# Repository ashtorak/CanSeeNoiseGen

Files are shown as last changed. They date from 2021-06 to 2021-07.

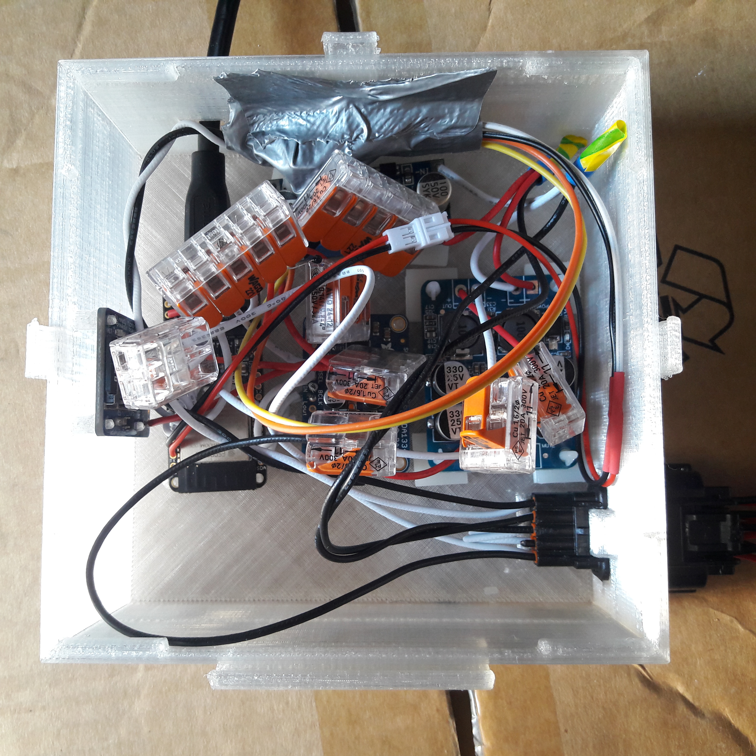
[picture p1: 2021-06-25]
Hardware/20210617_185216.jpg

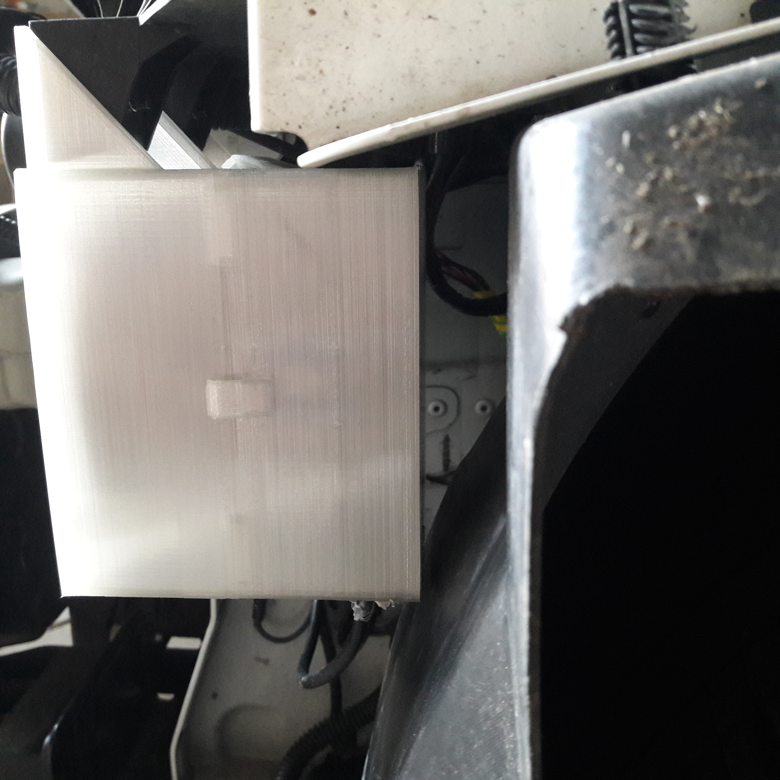
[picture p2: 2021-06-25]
Hardware/20210617_202823.jpg

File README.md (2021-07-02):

# CanSeeNoiseGen
CanSee with Vehicle Noise Generator 3.0 add-on for Renault Zoe (pre 2019 models)

This is an ESP32 project using VSCode with PlatformIO (Arduino framework), CirculaBuffer library and SdFat library. With the latter the build gets too large to use the standard build partition size, so I had to use a custom.csv in the platformio.ini where I set the partition size to 0x200000. See bottom for installation details.  
In my ini I also put some monitor flags and filters, which I tried out for debugging and testing. This is only for the serial interface via USB.

Everything is based on the wonderful work by Jeroen Meijer and co.: https://gitlab.com/jeroenmeijer/cansee

You can connect it to the "V-bus" at the diagnostic OBD port in the car or to the "E-bus" which goes directly to the Zoe VSP (https://canze.fisch.lu/the-pedestrian-horn/)
This NoiseGen software is set up for the E-bus. If you want to use the V-bus, you have to change the code in ticker10ms() in CanSee.ino.  
On E-bus not the same values are sent or different IDs are used. So CanZe won't display all the values.

This has been tested on a 2014 Q210. No guarantee that it works on other models.  
On 2019 or newer models a noise generator is mandatory and an off-switch is not allowed, afaik.

There is an integration with CanZe app in development to control the Noise Generator via bluetooth. But I haven't decided yet what to do with it. I might just release the .apk here.  
In any case, you can use a bluetooth terminal app and send text commands there. See CanSee.ino for reference.

---

**More technical remarks:**

I have to check how to properly connect the I2S board to the ESP. It seems very sensitive, producing crackling on the audio output easily. The best was to make the wires as short as possible. I also found that connecting the AGND directly to the GND of the ESP board seems to help. I am not sure, why.  
The manual for the ESP says to put pullup resistors at the I2S pins. But this didn't do anything for me.

Regarding SD card reading speed, I have tried different boards and combinations and found that the used components give the best speeds up to 25 MHz. If it is too slow (10 MHz), there will be errors when several samples are played in parallel.

---

Short video with some explanations: https://youtu.be/ppg4cpuIZtI

Thread in German Zoe forum with more info in German: https://www.goingelectric.de/forum/viewtopic.php?f=63&t=52091&p=1571585#p1571585

---

**Installation instructions:**

Warning: All here is work in progress. Don't expect everything working right out of the box. Programming experience is necessary. If something is unclear, open an issue or go to the forum.

1. Install VSCode.
2. In VSCode install the PlatformIO IDE extension. 
3. Go to PlatformIO Home (there should appear a bar at the bottom with a house). Then in "Open Project" select this whole folder from Github. Then it should install also the libraries by itself from platformio.ini. Else, you can install them in PIO Home. Also, sometimes it might be necessary to close and open VSCode again so that it finds all the dependencies. 
4. Copy custom.csv to \.platformio\packages\framework-arduinoespressif32\tools\partitions (the program is so large that it needs more memory than default)
5. Connect ESP32 via USB.
6. Build the project and upload it with the buttons on the PIO bar at the bottom.
7. For programming look into CanSee.ino and audiohandler.cpp in the src folder. The file names to load from the SD card are hard coded in the audiohandler. 22050 Hz @ 16 bit audio files are used. You can find the samples in the hardware folder. Just copy the folder content to the SD card.

With the PlatformIO: Serial Monitor or a bluetooth terminal, you can monitor some parameters and give commands that are defined in CanSee.ino.

Attention: The ESP32 and the programm store some configurations options on an EEPROM. For example, you can switch on and off bluetooth and it keeps the state also during power off. When you start the ESP and you don't have bluetooth or the serial output available, it might just be configured like this. See config.cpp for the initial configuration. If you change this configuration later on and upload it to the ESP, in order to actually load the new settings into the EEPROM you have to use the special function setConfigToEeprom(true) or 'z' via the terminal.

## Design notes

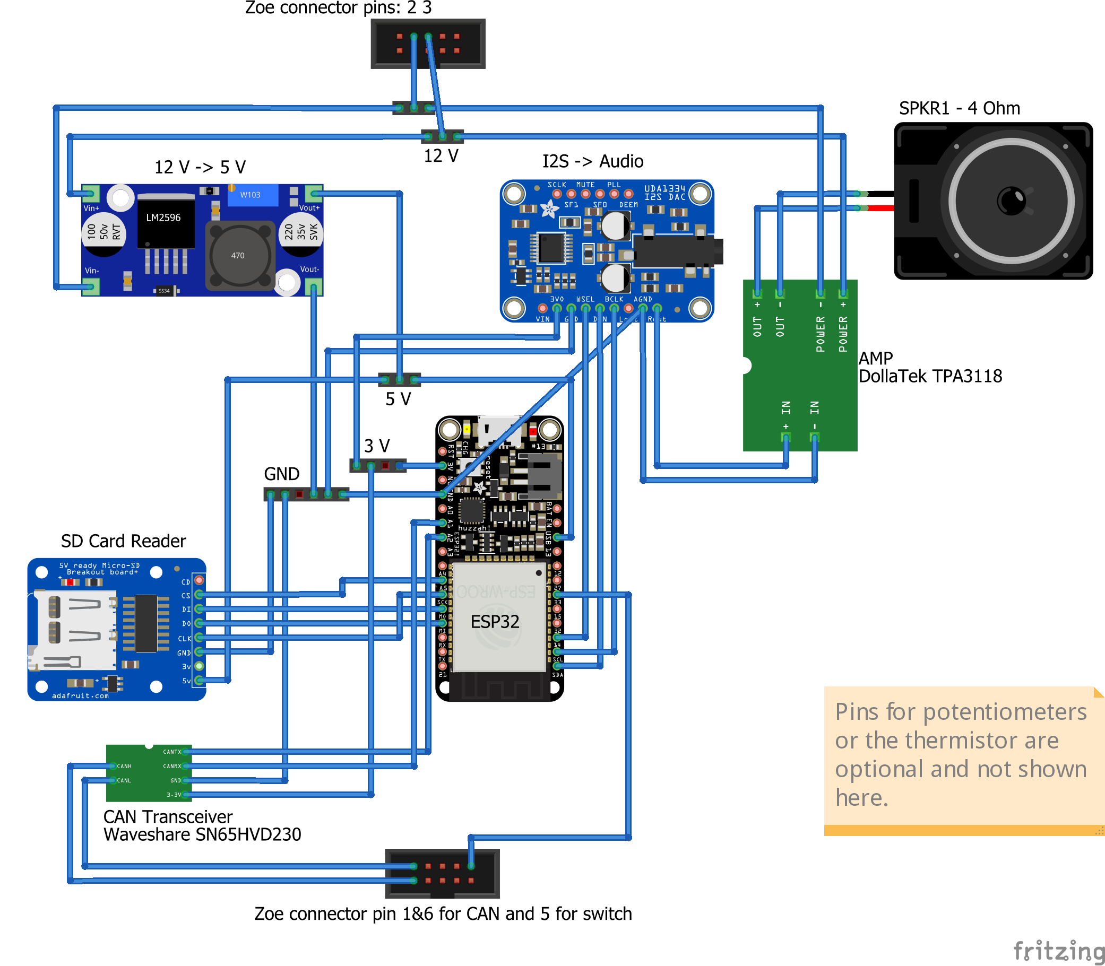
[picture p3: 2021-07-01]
Hardware/schematic.png

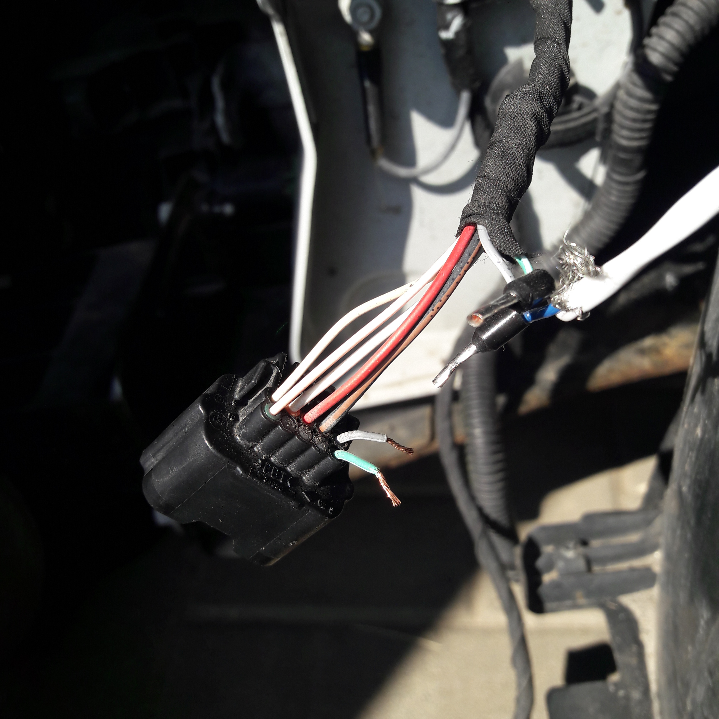
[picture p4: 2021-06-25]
Hardware/ZOE plug.jpg

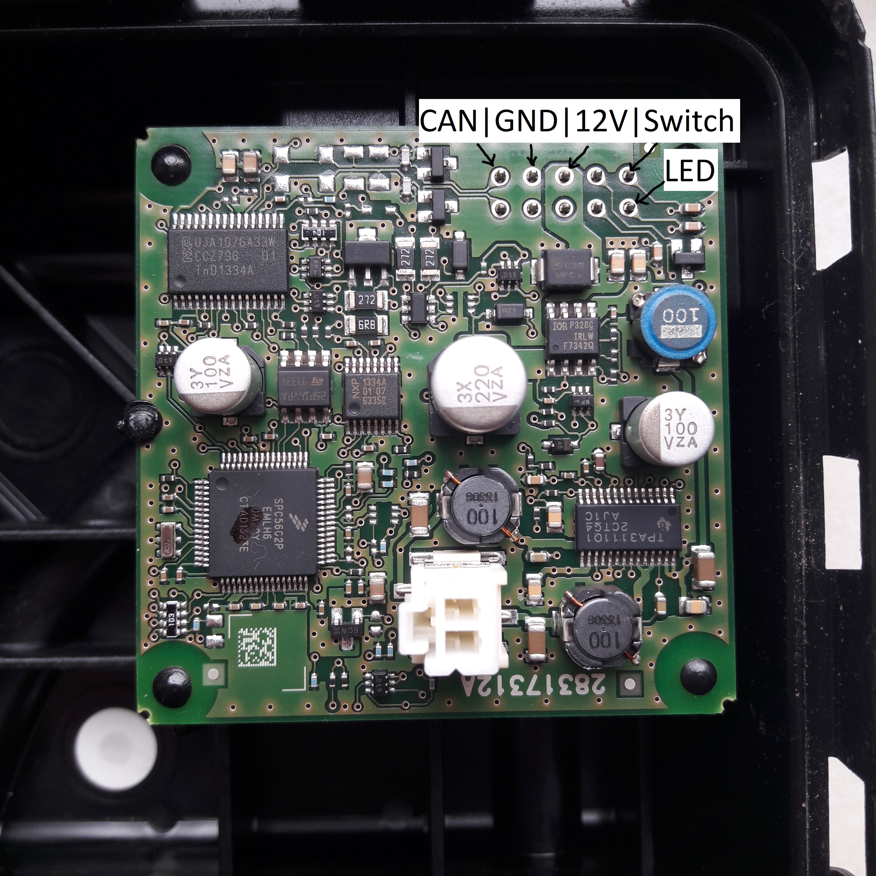
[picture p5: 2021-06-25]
Hardware/ZOE original VSP annotated.jpg

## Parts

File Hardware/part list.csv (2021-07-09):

part | manufacturer number | price in Euro | link
12 V ? 5V | AZDelivery LM2596S | 2,26 € | https://www.amazon.de/gp/product/B07YWLCTLK
I2S Stereo Decoder | Adafruit UDA1334A | 14,90 € | https://www.amazon.de/gp/product/B079GB1Z1M
ESP32 | Adafruit HUZZAH32 | 29,96 € | https://www.amazon.de/gp/product/B0743FNXK5
AMP | DollaTek TPA3118 | 6,99 € | https://www.amazon.de/gp/product/B07DJV4TQ4
SD card reader | Adafruit Micro SD Card Breakout Board+ | 18,56 € | https://www.amazon.de/gp/product/B00G71SN5A
CAN transceiver | Waveshare SN65HVD230 | 12,99 € | https://www.amazon.de/gp/product/B00KM6XMXO
plug | 2sets 10pin auto männlichen elektrische stecker 7282-8856 wasserdichte verdrahtung kabel stecker 7282-8856-30 | 7,00 € | https://de.aliexpress.com/item/33029457017.html

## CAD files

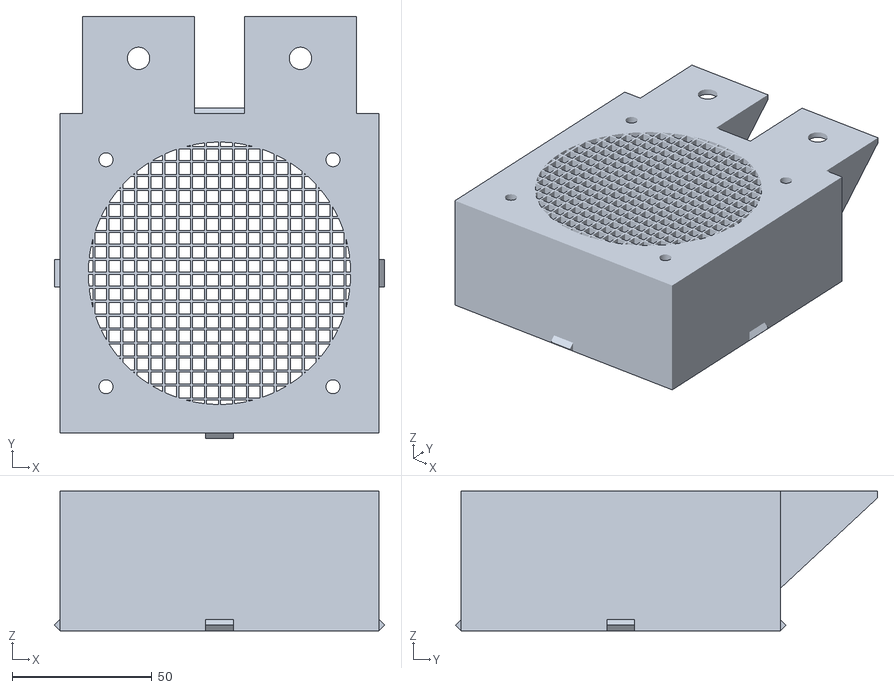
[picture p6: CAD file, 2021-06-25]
Hardware/3d-model-case-speaker.stl
118.4 x 151.2 x 50.0

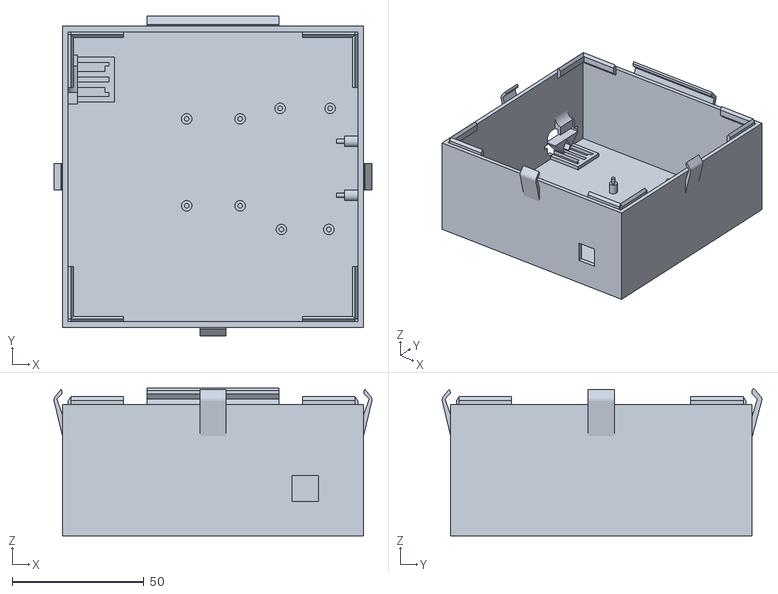
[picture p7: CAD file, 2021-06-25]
Hardware/3d-model-case-electronics.stl
120.8 x 121.4 x 56.2

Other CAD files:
Hardware/3d-freecad-model-case.FCStd

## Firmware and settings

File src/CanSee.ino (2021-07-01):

/*
CanSee with Vehicle Noise Generator add-on

This is based on "The firmware to the DIY, superfast, ESP32 based
comapanion to CANZE dongle" by - The CanZE Team: http://canze.fisch.lu

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
You should have received a copy of the GNU General Public License
along with this program.  If not, see <http://www.gnu.org/licenses/>.
*/

#define VERSION "004"
/* This is using an older CanSee version. It works on a 2014 Q210.
It should work with all Phase 1 ZOEs.
I removed all the LED code, as they are not used for the Noise Generator
*/

#define SERIAL_BPS 115200

/* 

My board: Adafruit HUZZAH32 - ESP32 Feather

CAN bus:
ESP32 GPIO 16 - RX - CAN
ESP32 GPIO 17 - TX - CAN

SD card pins:
ESP32 GPIO 4 - A5 - CS
ESP32 GPIO 5 - SCK
ESP32 GPIO 19 - MI - MISO
ESP32 GPIO 18 - MO -  MOSI

I2S pins:
ESP32 GPIO 22 - SCL - Bit Clock
ESP32 GPIO 14 - A6 - wclk, Left/Right Clock
ESP32 GPIO 23 - SDA - Data Out

Misc pins:
ESP32 GPIO 25 - A1 - potiPin1 (see audiohandler)
ESP32 GPIO 26 - A0 - potiPin2 or for Thermistor
ESP32 GPIO 33 - A9 - sampleSetSelectorPin

*/

// Our own includes, see ./include/ ******************************************
#include "Arduino.h"
#include "config.h"
#include "canhandler.h"
#include "serialhandler.h"
#include "bluetoothhandler.h"
#include "wifihandler.h"
#include "freeframehandler.h"
#include "isotphandler.h"
#include "utils.h"
#include "audiohandler.h"

// for reading out bus values ************************************************
FREEFRAME_t *freeframe;
int byte1 = 0;
int byte2 = 0;
bool pollFrame = false;
int pollFrameId;

// Temperature measurement with thermistor ***********************************
static bool usethermistor = true;
// which analog pin to connect
#define THERMISTORPIN A0         
// resistance at 25 degrees C
#define THERMISTORNOMINAL 10000      
// temp. for nominal resistance (almost always 25 C)
#define TEMPERATURENOMINAL 25   
// how many samples to take and average, more takes longer
// but is more 'smooth'
#define NUMTEMPSAMPLES 5
// The beta coefficient of the thermistor (usually 3000-4000)
#define BCOEFFICIENT 3950
// the value of the 'other' resistor
#define SERIESRESISTOR 10000    

int temperature_samples[5];

// For Zoe capacitive switch for sample selection ****************************

#include <CircularBuffer.h> // add via PlatformIO manager
// it probably could be done without this library but I used it for testing and kept it
static const int touchBuffersize = 50;
/* The touchRead() function reads a number of sawtooths on a pin to see if the 
  capacity changes. The readings fluctuate quite a bit. So it's necessary to 
  average over larger number of samples which are stored in this buffer
*/
CircularBuffer<int, touchBuffersize> touchBuffer;
static const int sampleSetSelectorPin = 33;
int avg;

// Tidy up defs **************************************************************
#if !defined(CONFIG_BT_ENABLED) || !defined(CONFIG_BLUEDROID_ENABLED)
#error Bluetooth is not enabled! Please run `make menuconfig` to and enable it
#endif

// Config ********************************************************************
CS_CONFIG_t *cansee_config;

// Command structure that defines a textual incoming command *****************
typedef struct
{
  char cmd;
  uint32_t id = 0;
  uint8_t request[32];
  uint16_t requestLength = 0;
  uint8_t reply[32];
  uint16_t replyLength = 0;
  char line[48];
} COMMAND_t;

// additional command stuff  *************************************************
String readBuffer = "";
bool pedalCommand = false; // from bluetooth, for sound mod
bool debugaudio = false; // can be changed by command 'x'

//* counters *****************************************************************
uint32_t canFrameCounter = 1;
uint32_t lastCanFrameCounter = 0;
uint32_t cnt5000 = 0;
uint32_t cnt100 = 0;

// ***************************************************************************
void setup()
{
  Serial.begin(SERIAL_BPS); // init serial
  Serial.println("");
  Serial.println(":D");
  Serial.println("CANSee starting...");

  cansee_config = getConfig(); // invalid config will reset too

  cansee_config->output_handler = writeOutgoing;
  cansee_config->command_handler = processCommand;

  if (cansee_config->mode_debug)
  {
    Serial.print("Version:   ");
    Serial.println(VERSION);
    Serial.println("Serial:    " + getHex(cansee_config->mode_serial));
    Serial.println("Bluetooth: " + getHex(cansee_config->mode_bluetooth));
    Serial.println("WiFi:      " + getHex(cansee_config->mode_wifi));
    Serial.println("Debug:     " + getHex(cansee_config->mode_debug));
    Serial.println("CANbus0:   " + getHex(cansee_config->can0_speed / 25) + getHex(cansee_config->can0_rx) + getHex(cansee_config->can0_tx));
    //Serial.println("CANbus1*   " + getHex(cansee_config->can1_speed / 25) + getHex(cansee_config->can1_rx) + getHex(cansee_config->can1_tx));
    Serial.println("Boot count:" + getHex(cansee_config->boot_count));
  }
  cansee_config->boot_count++;

  setConfigToEeprom(false); // use command 'z' during operation to update Eeprom

  serial_init();
  bluetooth_init();
  wifi_init();

  can_init();
  freeframe_init();
  isotp_init();

  audio_init();

  // for measuring as long as possible on Zoe switch
  touchSetCycles(0x9999,0x10);
}

// ***************************************************************************
void loop()
{
  tickerFast();
}

void tickerFast()
{
  uint32_t nowMicros = micros();
  static uint32_t lastMicros = nowMicros; // static so should only be initalized once

  // do Fast
  CAN_frame_t rx_frame; // 1. receive next CAN frame from queue
  if (can_receive(&rx_frame))
  {
    storeFrame(rx_frame);
    canFrameCounter++;
  }
  readIncoming(); // 2. proceed with input (serial & BT)
  isotp_ticker();
  
  audio_fast();
  
// end do Fast

  if ((nowMicros - lastMicros) > 10000L)
  { // 10 ms passed?
    ticker10ms();
    //lastMicros = nowMicros;
    lastMicros += 10000L;
  }
}

void ticker10ms()
{
  static int pedal = 0;

  if(!pedalCommand) // sent via bluetooth
  {
    // get pedal data from e-bus
    freeframe = getFreeframe(0x436, 0);
    pedal = freeframe->data[4];
  }
  else
  { // play sample once with this pedal position (e.g. for horse whinny)
    pedalCommand = false;
    pedal = 100;
  }
  
  // get rpm data from e-bus
  static int elecRPM = 0;
  freeframe = getFreeframe(0x19f, 0); // bits 16 to 27
  byte1 = freeframe->data[2];
  byte2 = freeframe->data[3];
  if(byte1==0) elecRPM = 0; // when not connected to bus
  else elecRPM = abs((byte1<<4 | byte2>>4)*10-20000); 
     
  // get pedal data from v-bus
  // freeframe = getFreeframe(0x186, 0); // position of accelerator pedal, from bit 40 to 48, range 0...250
  // pedal = freeframe->data[5];
    
  // get rpm data from v-bus
  // freeframe = getFreeframe(1f8, 0); // 0x1f8, from bit 40 up to and including 50, range 0...1200 (multiply by 10 for rpm)
  // byte1 = freeframe->data[5]; // bit 40 to 47
  // byte2 = freeframe->data[6]; // bit 48 to 55
  // elecRPM = (byte1<<3 | byte2>>5)*10; // combine 0111 1111 1000 and 0111    

  audio_soundModulator(pedal, elecRPM);
  
  touch();
  
  static int tick = 0;
  
  if (++tick == 100)
  { 
    ticker1000ms();
    tick = 0;
    //Serial.println(sampleSet);
  }
  if(tick==10 && debugaudio)
  {  
    writeOutgoing(audio_debug1());
    writeOutgoing(audio_debug2());
    writeOutgoing("avg: " + String(avg) + "\n");
  }

  // poll a frame (with 'p')
  if(pollFrame)
  {
    requestFreeframe(pollFrameId, 0);
  }
}

void ticker1000ms()
{
  static int tick = 0;

  // do every 1000ms

  // end do every 1000 ms

  if (++tick == 5)
  {
    ticker5000ms();
    tick = 0;
  }

  if (debugaudio && usethermistor)
  {
    static uint8_t i;
    static float average;

    // take N samples in a row, with a slight delay
    for (i=0; i< NUMTEMPSAMPLES; i++) {
    temperature_samples[i] = analogRead(THERMISTORPIN);
   // delay(10);
    }
    
    // average all the samples out
    average = 0;
    for (i=0; i< NUMTEMPSAMPLES; i++) {
      average += temperature_samples[i];
    }
    average /= NUMTEMPSAMPLES;

   // Serial.print("Average analog reading "); 
   // Serial.println(average);
    
    // convert the value to resistance
    average = (4095-200) / average - 1;
    average = SERIESRESISTOR / average;
   // Serial.print("Thermistor resistance "); 
   // Serial.println(average);
    
    float steinhart;
    steinhart = average / THERMISTORNOMINAL;     // (R/Ro)
    steinhart = log(steinhart);                  // ln(R/Ro)
    steinhart /= BCOEFFICIENT;                   // 1/B * ln(R/Ro)
    steinhart += 1.0 / (TEMPERATURENOMINAL + 273.15); // + (1/To)
    steinhart = 1.0 / steinhart;                 // Invert
    steinhart -= 273.15;                         // convert absolute temp to C
    
   // Serial.print("Temperature "); 
  //  Serial.print(steinhart);
  //  Serial.println(" *C");
  writeOutgoing("temperature: " + String(steinhart) + "\n");
  }
}

void ticker5000ms()
{
  // do every 5000ms
  setActiveBluetooth(canFrameCounter != lastCanFrameCounter);
  ageFreeFrame();
  // end do every 5000 ms
}

/*****************************************************************************
* frame handling function
*/

void storeFrame(CAN_frame_t &frame)
{
  if (frame.MsgID < 0x700)
  { // free data is < 0x700
    storeFreeframe(frame, 0);
  }
  else
  { // iso-tp data is < 0x800
    storeIsotpframe(frame, 0);
  }
}

// I/O functions *************************************************************

void writeOutgoing(String o)
{
  writeOutgoingSerial(o);
  writeOutgoingBluetooth(o);
  writeOutgoingWiFi(o);
}

void readIncoming()
{
  readIncomingSerial(readBuffer);
  readIncomingBluetooth(readBuffer);
  readIncomingWiFi(readBuffer);
}

// execute a command *********************************************************
void processCommand()
{
  uint8_t bus = 0;

  if (cansee_config->mode_debug & DEBUG_COMMAND)
    Serial.println("< com:" + readBuffer);
  COMMAND_t command = decodeCommand(readBuffer); // watch out, passe dby reference, so eaten

  //bus = (command.id & 0x40000000) ? 1 : 0;
  //command.id &= 0x1fffffff;                        // allow for 29 bits CAN later

  switch (command.cmd)
  {

  // output all buffered frames ********************************************
  case 'a':
  {
    int count = 0;
    
    for (uint32_t id = 0; id < FREEFRAMEARRAYSIZE; id++)
    {
      freeframe = getFreeframe(id, bus); // bus is ignored for free frames
      if (freeframe->age)
      { // print length 0 frames, but do not print timeout frames
        //writeOutgoing (bufferedFrameToString (id, bus)); // includes \n
        requestFreeframe(id, bus);
        count++;
      }
    }
    if (cansee_config->mode_debug & DEBUG_COMMAND)
      Serial.println("> fcn:" + String(count));
  }
  break;

  // get a frame ***********************************************************
  case 'g':
    if (command.id < FREEFRAMEARRAYSIZE)
    {
      requestFreeframe(command.id, bus);
    }
    else
    {
      if (cansee_config->mode_debug & DEBUG_COMMAND)
        Serial.print("> com:ID out of bounds (0 - 0x6ff)");
      requestFreeframe(0, bus);
    }
    break;

  // request an ISO-TP frame ***********************************************
  case 'i':
    if (command.id >= 0x700)
    {
      requestIsotp(command.id, command.requestLength, command.request, bus);
    }
    else
    {
      if (cansee_config->mode_debug)
        Serial.println("E:ID out of bounds (0x700 - 0x7ff)");
      requestIsotp(0, 0, 0, 0);
    }
    break;

  // inject a frame via serial / BT input **********************************
  case 't':
  {
    CAN_frame_t frame;
    frame.MsgID = command.id;
    frame.FIR.B.DLC = command.requestLength;
    for (int i = 0; i < command.requestLength; i++)
      frame.data.u8[i] = command.request[i];
    if (cansee_config->mode_debug & DEBUG_COMMAND)
      Serial.print("> com:Injecting " + canFrameToString(frame));
    storeFrame(frame);
    // storeframe will output if free frame or ISO-TP Single
    // writeOutgoing (getHex (command.id) + "\n");
  }
  break;

  // config (see config.cpp) ***********************************************
  case 'n':
    if (cansee_config->mode_debug & DEBUG_COMMAND)
      Serial.println("> com:config " + getHex(command.id));
    switch (command.id)
    {
    case 0x100: // set mode flags
      cansee_config->mode_serial = command.request[0];
      cansee_config->mode_bluetooth = command.request[1];
      cansee_config->mode_wifi = command.request[2];
      cansee_config->mode_debug = command.request[3];
      break;
    case 0x101: // get mode flags
      writeOutgoing(getHex(command.id) + "," + getHex(cansee_config->mode_serial) + getHex(cansee_config->mode_bluetooth) + getHex(cansee_config->mode_wifi) + getHex(cansee_config->mode_debug) + "\n");
      return;
      break;
    case 0x110: // set only serial flag
      cansee_config->mode_serial = command.request[0];
      break;
    case 0x114: // set only debug flags
      cansee_config->mode_debug = command.request[0];
      break;
    case 0x200:
      strncpy(cansee_config->name_bluetooth, command.line + 5, sizeof(cansee_config->name_bluetooth));
      break;
    case 0x201:
      strncpy(cansee_config->pin_bluetooth, command.line + 5, sizeof(cansee_config->pin_bluetooth));
      break;
    case 0x300:
      strncpy(cansee_config->ssid_ap, command.line + 5, sizeof(cansee_config->ssid_ap));
      break;
    case 0x301:
      strncpy(cansee_config->password_ap, command.line + 5, sizeof(cansee_config->password_ap));
      break;
    case 0x400:
      strncpy(cansee_config->ssid_station, command.line + 5, sizeof(cansee_config->ssid_station));
      break;
    case 0x401:
      strncpy(cansee_config->password_station, command.line + 5, sizeof(cansee_config->password_station));
      break;
    case 0x500: // can0
      cansee_config->can0_speed = command.request[0] * 25;
      cansee_config->can0_rx = command.request[1];
      cansee_config->can0_tx = command.request[2];
      break;
    case 0x501: // can1
      cansee_config->can1_speed = command.request[0] * 25;
      cansee_config->can1_rx = command.request[1];
      cansee_config->can1_tx = command.request[2];
      break;
    }
    setConfigToEeprom(false);
    writeOutgoing(getHex(command.id) + "\n");
    break;

  // send a value for testing*************************************************
  case 'o':
    audio_test(command.id,0,0);
  break;

  // enable/disable frame polling ********************************************
  case 'p':
  {
    if (command.id < FREEFRAMEARRAYSIZE)
    {
      pollFrameId = command.id;
      if (pollFrameId == 0) pollFrame = false;
      else pollFrame = true;
    }
  }
  break;

  // send a value for testing*************************************************
  case 'q':
    audio_test(0,command.id,0);
  break;

  // reset config & reboot **************************************************
  case 'r':
    ESP.restart();
  break;

  // sample select **********************************************************
  case 's':
    audio_selectSampleSet(command.id);
  break;

  // adjust global volume ***************************************************
  case 'v':
    if(command.id<16) audio_setVolume(command.id);
    else audio_setVolume(command.id-6);
  break;

  // medium pedal press for sound simulation (whinny)************************
  case 'w':
    pedalCommand = true;
  break;

  // write audio info to outgoing********************************************
  case 'x':
    debugaudio=!debugaudio;
  break;

  // send a value for testing************************************************
  case 'y':
    audio_test(0,0,command.id);
  break;

  // reboot *****************************************************************
  case 'z':
    setConfigToEeprom(true);
    ESP.restart();
    break;

  // give up ****************************************************************
  default:
    if (cansee_config->mode_debug)
      Serial.println("> com:Unknown command " + String(command.cmd));
    writeOutgoing("fff,\n");
    break;
  }
}

// parse a string into a command *********************************************
COMMAND_t decodeCommand(String &input)
{
  COMMAND_t result;
  result.id = 0; // clear out older data
  result.requestLength = 0;
  result.replyLength = 0;

  input.trim(); // trim whitespaces
  strncpy(result.line, input.c_str(), sizeof(result.line));

  if (input.length() == 0)
    return result; // stop if input is empty

  result.cmd = input.charAt(0); // the first letter is the command
  input.remove(0, 1);

  if (input.length() != 0)
  {          // if there is something more,
    char ch; // get the ID
    String id = "";
    do
    {
      ch = input.charAt(0);
      if (ch != ',')
        id += ch;
      input.remove(0, 1);
    } while (input.length() != 0 && ch != ',');
    result.id = hexToDec(id);
  }

  if (input.length() != 0)
  {          // if there is something more,
    char ch; // get the REQUEST
    String request = "";
    do
    {
      ch = input.charAt(0);
      if (ch != ',')
        request += ch;
      input.remove(0, 1);
    } while (input.length() != 0 && ch != ',');
    for (int i = 0; i < request.length() && result.requestLength < 32; i += 2)
    { // check for overflow
      result.request[result.requestLength] = hexToDec(request.substring(i, i + 2));
      result.requestLength++;
    }
  }

  if (input.length() != 0)
  {          // if there is something more,
    char ch; // get the REPLY
    String reply = "";
    do
    {
      ch = input.charAt(0);
      if (ch != ',')
        reply += ch;
      input.remove(0, 1);
    } while (input.length() != 0 && ch != ',');
    for (int i = 0; i < reply.length() && result.replyLength < 32; i += 2)
    { // check for overflow
      result.reply[result.replyLength] = hexToDec(reply.substring(i, i + 2));
      result.replyLength++;
    }
  }
  return result;
}

// check Zoe switch with ESP32 touch functionality
void touch() {

  touchBuffer.push(touchRead(sampleSetSelectorPin));
  
  static int total = 0;

	for (int i = 0; i <touchBuffersize; i++) {
	total += touchBuffer[i];
	}

  avg = total / (touchBuffersize);
  total=0;

  // prevent double switching with timer
  static int timer=0;
  static boolean ready=false; // to not switch on startup
  if(!ready && timer<60) timer++; // timer in tens of millisesconds
  else ready = true;

  if(avg<11 && ready) // avg touch read value might vary slightly between cars (unconfirmed)
  {
    audio_changeSample();
    timer = 0;
    ready = false;
  }

}

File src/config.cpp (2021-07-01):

#include "config.h"
#include "CAN_config.h"

static CS_CONFIG_t cs_config;
static bool fetched = false;

void setConfigDefault_3 () {
  cs_config.version                   = 3;         // change if length of config changes
  cs_config.can0_rx                   = RX;
  cs_config.can0_tx                   = TX;
  cs_config.can0_speed                = (uint16_t)CAN_SPEED_1000KBPS;
  /* On ESP32 Rev. 3 can bus speed needs to be set to twice the old value. Before it was 500KBPS.
  See https://gitlab.com/jeroenmeijer/cansee/-/issues/17 or 
  https://www.esp32.com/viewtopic.php?t=15581
  */
  cs_config.can1_rx                   = GPIO_NUM_36;
  cs_config.can1_tx                   = GPIO_NUM_39;
  cs_config.can1_speed                = (uint16_t)CAN_SPEED_250KBPS;
}

void setConfigDefault_4 (bool reset_boot_count) {
  cs_config.version                   = 4;         // change if length of config changes
  if (reset_boot_count)
    cs_config.boot_count              = 0;
}

void setConfigRam () {
  cs_config.bus = 0;
  cs_config.command_handler = NULL;
  cs_config.output_handler = NULL;
  fetched = true;
}

void setConfigDefault () {
  cs_config.magicnumber = 0x0caacee0;              // does that read CanSee?
  cs_config.version                   = 1;         // change if length of config changes
  cs_config.mode_serial               = 1;
  cs_config.mode_bluetooth            = 1;
  cs_config.mode_wifi                 = 0;         // WIFI_SOFTAP or WIFI_STATION;
  cs_config.mode_debug                = 0xf6;
  strcpy (cs_config.name_bluetooth,   "CANSee");
  strcpy (cs_config.pin_bluetooth,    "1234");     // not implemented in framework yet
  strcpy (cs_config.ssid_ap,          "CANSee");
  strcpy (cs_config.password_ap,      "CANSeeMe");
  strcpy (cs_config.ssid_station,     "");
  strcpy (cs_config.password_station, "");
  setConfigDefault_3 ();
  setConfigDefault_4 (false);
  setConfigRam ();
}

CS_CONFIG_t *getConfig () {
  if (fetched) return &cs_config;
  if (!EEPROM.begin (sizeof (CS_CONFIG_t))) {
    Serial.println ("failed to initialise EEPROM for reading");
    setConfigDefault ();
    setConfigRam ();
    return &cs_config;
  }
  if (EEPROM.readBytes (0, &cs_config, sizeof (CS_CONFIG_t)) != sizeof (CS_CONFIG_t) || cs_config.magicnumber != 0x0caacee0) {
    Serial.println ("Not a valid EEPROM record");
    setConfigToEeprom (true);
  }
  // so here we have a valid cs_config
  if (cs_config.version < 3) {
    Serial.println ("EEPROM structure changed");
    EEPROM.end ();
    setConfigDefault_3 ();
    setConfigToEeprom (false);
  } else if (cs_config.version < 4) {
      Serial.println ("EEPROM structure changed");
      EEPROM.end ();
      setConfigDefault_4 (true);
      setConfigToEeprom (false);
  } else {
    EEPROM.end ();
  }
  // Clear ram components
  setConfigRam ();
  return &cs_config;
}

void setConfigToEeprom (bool reset) {
  if (!EEPROM.begin (sizeof (CS_CONFIG_t)))
  {
    Serial.println ("failed to initialise EEPROM for writing");
    return;
  }
  if (reset) setConfigDefault ();
  EEPROM.writeBytes (0, &cs_config, sizeof (CS_CONFIG_t));
  EEPROM.commit ();
  EEPROM.end ();
  return;
}

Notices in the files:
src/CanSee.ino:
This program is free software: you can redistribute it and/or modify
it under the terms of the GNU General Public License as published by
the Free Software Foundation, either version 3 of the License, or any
